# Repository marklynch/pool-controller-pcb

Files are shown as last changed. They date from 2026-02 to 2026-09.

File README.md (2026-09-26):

# Pool Controller PCB

KiCad design for a Connect 10 compatible pool-bus interface, using the finished **Waveshare ESP32-C6 Mini Development Board (ESP32-C6-Zero)** plugged into a carrier socket. The board provides a 5 V buck supply and single-wire receive/transmit interface. Firmware is maintained in [pool-controller-code](https://github.com/marklynch/pool-controller-code).

## Current revision

**Revision 15 is a prototype for validation.** It adds the 3.3 V RX clamp from [issue #3](https://github.com/marklynch/pool-controller-pcb/issues/3) and changes the TX base resistor to 560 Ω as proposed in [issue #4](https://github.com/marklynch/pool-controller-pcb/issues/4). It retains the existing 80 × 75 mm outline and 1.2 mm thickness.

The RX clamp requires the Waveshare 3.3 V rail and does not provide power-off isolation. Confirm operation during boot/reset/shutdown and at both 7 V and 12 V data-high levels before field use. The power-supply design report's detailed operating point is **5 V / 0.5 A**; a 5 A regulator IC does not make this a 5 A board.

See [revision 15 assembly and acceptance](docs/rev15-assembly.md) before ordering. J1/J2 now specify distributor-stocked Ckmtw R-RJ11R06P-A000 (LCSC C2902699), with a matching new footprint and connector routing. The original case has a 1.3 mm PCB slot, so retain the 1.2 mm board. Its RJ12 openings need enlargement: see [enclosure fit and same-case variant](docs/rev15-enclosure.md). Confirm snap-peg retention on the 1.2 mm board with PCBWay. The Waveshare boards have already been purchased separately; PCBWay should supply the soldered carrier and its two Samtec socket strips, with no additional module purchase.

## Files

- `PoolController.kicad_pro`, `.kicad_sch`, `.kicad_pcb`: source project, schematic and routed PCB.
- `components/`: project-specific symbols, footprints and existing 3D models.
- `docs/`: component/design references and prototype assembly instructions.
- `manufacturing/rev15/`: revision-specific sample-order exports and validation record.
- `scripts/export-manufacturing.sh`: reproduce manufacturing exports using KiCad 9.

Use **KiCad 9** to open and validate the project. Custom library paths are relative to the project. A 3D model is not a substitute for checking the dimensions and pin mapping of the actual purchased part.

## Ordering prototypes

For PCBWay, use `PCBWay-BOM.csv` (carrier parts only; Waveshare boards are customer-supplied) and `PCBWay-SMT-CPL.csv`. Read the assembly notes, confirm exact-part allocation and module installation, and review their DFM and placement previews before authorizing fabrication/assembly. Gerbers and drill files cover the bare board; the BOM, placement file and assembly drawing define fitted carrier parts. Fit the customer-owned module after delivery, or arrange consignment and separately quote installation/programming with PCBWay.

Physical checks, supplier approval, firmware programming and functional testing are distinct from KiCad ERC/DRC. Generated files are a prototype build package, not proof of field reliability.

## Licence

Hardware designs are licensed under the CERN Open Hardware Licence Version 2 — Permissive; see [LICENCE](LICENCE). See [CHANGELOG.md](CHANGELOG.md) for revision history.

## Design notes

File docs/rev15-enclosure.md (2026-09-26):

# Rev15 enclosure fit

Retain **1.2 mm PCB thickness**. The author's [pool-controller-case](https://github.com/marklynch/pool-controller-case) `BoxV7.FCStd`, commit `222a908dec85139a257c31b71b18a0f9f9488ca6`, defines a **1.3 mm** PCB slot (Sketch005). A 1.6 mm board would not fit that nominal slot. The PCB author changed thickness from 1.6 to 1.2 mm in [commit 07033f0](https://github.com/marklynch/pool-controller-pcb/commit/07033f06fe821ae59426765578216f9a735abf40). The commit does not explain the reason; the case geometry independently supports retaining 1.2 mm. Allow for board-thickness tolerance and printed-slot fit.

The **unmodified case is not compatible with the current RJ12 body envelopes**. Its front sketch has two 13.25 × 11.5 mm openings; the Ckmtw connector bodies are nominally 13.21 × 12.7 mm across the front. Their centres also differ slightly from the old openings. Do not order a printed original case expecting a verified fit.

`scripts/prepare-enclosure.py` generates a variant of the same case with 15 × 13.5 mm RJ12 openings centred on the current connector envelopes. It preserves the case exterior, PCB slot, lid geometry and USB opening. The script requires the author's external CAD as input and checks its SHA-256 before applying cuts. The output includes STL, editable STEP, the unchanged lid STL if supplied alongside the source, and a geometric collision report. It does not change the original FreeCAD file.

Example, with Python and CadQuery 2.8 installed:

```sh
python scripts/prepare-enclosure.py /path/to/pool-controller-case/BoxV7.FCStd /path/to/enclosure-rev15
```

The collision check covers only the nominal board and approximate RJ12 body envelopes. The connector drawing omits an explicit body-to-tail offset; the whole module/USB/header stack is not modelled. The generated solid was valid; nominal board-to-case, board-to-lid and RJ12-envelope collision volumes were zero after enlargement. A passing check is **not complete assembly validation**. Print one case and check the actual two sockets, cable latch operation, header engagement, module/USB access and lid clearance before printing the batch. Samtec socket body height is 8.51 mm; keep this exact socket MPN. The user already owns the Waveshare modules and will fit them after carrier delivery.

The RJ12 drawing recommends a 1.6 mm PCB. Retaining the case-compatible 1.2 mm carrier therefore still needs flush seating during soldering and a retention check; a thinner board would not remove this exception. The updated purchasing instructions state this requirement explicitly.

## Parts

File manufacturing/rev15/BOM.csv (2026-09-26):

Designator | Comment | Footprint | Manufacturer | MPN | Quantity | Supplier | Supplier Part | Supplier URL | Procurement note
C1 | 10nF | Capacitor_SMD:C_0805_2012Metric | TDK | C2012C0G1H103J060AA | 1 | DigiKey / manufacturer stock locator |  | https://product.tdk.com/en/search/capacitor/ceramic/mlcc/info?part_no=C2012C0G1H103J060AA | TDK Production; manufacturer recommended successor, 5% tolerance.
C2,C3 | C 10uF/63v | Capacitor_SMD:C_1210_3225Metric | Samsung Electro-Mechanics | CL32B106KMVNNWE | 2 | DigiKey |  | https://www.digikey.com/en/products/detail/samsung-electro-mechanics/CL32B106KMVNNWE/7320558 | Active distributor listing. 10uF 63V X7R; maximum height 2.8mm. Exact part only; qualify input ripple at 40V on samples.
C4 | 100nF/50v | Capacitor_SMD:C_0805_2012Metric | Kemet | C0805C104M5RACTU | 1 | DigiKey |  | https://www.digikey.com/en/products/detail/kemet/C0805C104M5RACTU/411168
C5 | C 47uF/16v | Capacitor_SMD:C_1210_3225Metric | Samsung Electro-Mechanics | CL32A476KOJNNNE | 1 | DigiKey |  | https://www.digikey.com/en/products/detail/samsung-electro-mechanics/CL32A476KOJNNNE/3889034 | Samsung Mass Production. Exact part only; qualify power-stage startup/load transients on samples.
D1,D2 | PMEG6010CEH,115 | Diode_SMD:D_SOD-123F | Nexperia | PMEG6010CEH,115 | 2 | LCSC | C110797 | https://www.lcsc.com/product-detail/C110797.html
D3 | BAT54 | Package_TO_SOT_SMD:SOT-23 | Nexperia | BAT54,215 | 1 | LCSC | C85084 | https://www.lcsc.com/product-detail/C85084.html
J1,J2 | RJ12 | PoolController:RJ12_Ckmtw_R-RJ11R06P-A000 | Ckmtw | R-RJ11R06P-A000 | 2 | LCSC | C2902699 | https://www.lcsc.com/product-detail/C2902699.html | 6P6C, tab down, right angle. Use new Ckmtw footprint only; original 5324 socket is not interchangeable. Verify retention on 1.2 mm PCB.
J3 | Header | Connector_PinHeader_2.54mm:PinHeader_1x04_P2.54mm_Vertical | XFCN | PZ254V-11-04P | 1 | LCSC | C2691448 | https://www.lcsc.com/product-detail/C2691448.html
J4,J5 | SSW-109-01-T-S | PoolController:Samtec_SSW-109-01-T-S_1x09 | Samtec | SSW-109-01-T-S | 2 | DigiKey |  | https://www.digikey.com/en/products/detail/samtec-inc/SSW-109-01-T-S/1112296 | Two 9-position socket strips per carrier; tin contacts and tails, 8.51mm body height. Do not substitute taller/shorter sockets without mechanical review.
L1 | L 120uH | Inductor_SMD:L_10.4x10.4_H4.8 | Bourns | SRR1050HA-121Y | 1 | DigiKey |  | https://www.digikey.com/en/products/detail/bourns-inc/SRR1050HA-121Y/16883859 | Active HA series; 245 C maximum reflow peak.
Q1 | MMBT3904 | MMBT3904:SOT-23_MCC | Guangdong Hottech | MMBT3904 | 1 | LCSC | C181119 | https://www.lcsc.com/product-detail/C181119.html | Use specified Guangdong Hottech manufacturer.
R1,R2,R4 | R100k | Resistor_SMD:R_0603_1608Metric | YAGEO | RC0603FR-07100KL | 3 | LCSC | C14675 | https://www.lcsc.com/product-detail/C14675.html
R3 | R560 | Resistor_SMD:R_0603_1608Metric | YAGEO | RC0603FR-07560RL | 1 | Mouser |  | https://au.mouser.com/en/ProductDetail/YAGEO/RC0603FR-07560RL | Mouser stock observed; DigiKey backordered at review. Confirm allocation.
U1 | LM2678S-5.0/NOPB | Package_TO_SOT_SMD:TO-263-7_TabPin4 | Texas Instruments | LM2678S-5.0/NOPB | 1 | DigiKey |  | https://www.digikey.com/en/products/detail/texas-instruments/LM2678S-5-0-NOPB/363825 | Confirm 245 C peak reflow limit and thermal-pad via treatment.

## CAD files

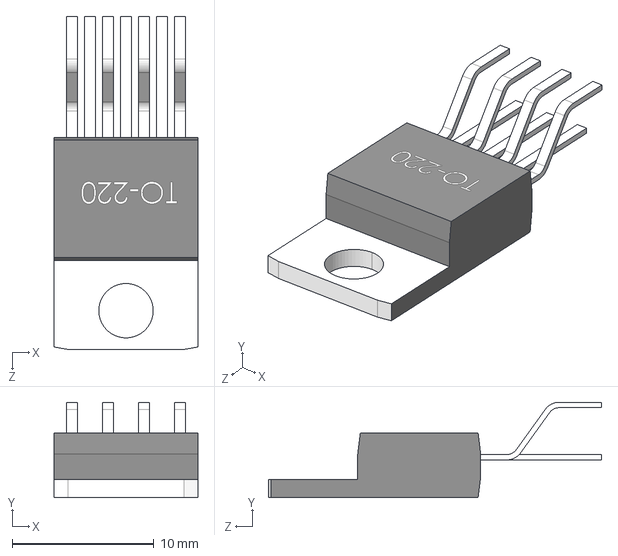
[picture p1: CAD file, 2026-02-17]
components/3dmodels/TO-220-7.step
10.2 x 6.74 x 23.5 mm

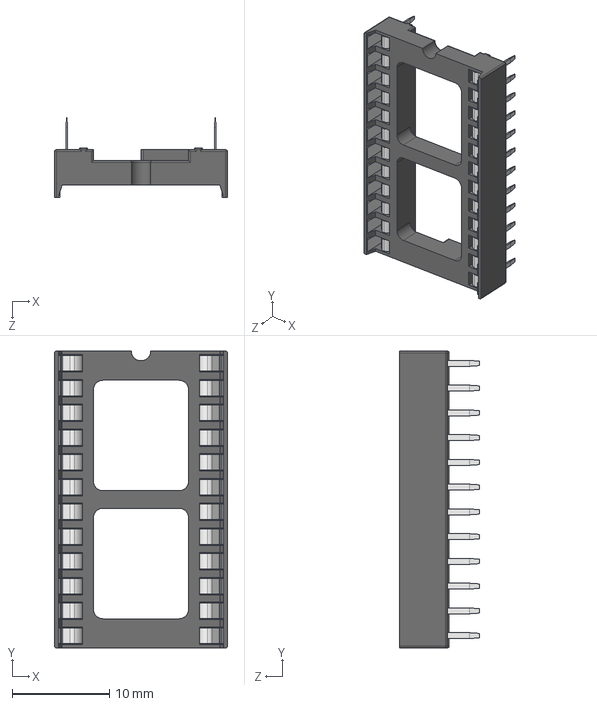
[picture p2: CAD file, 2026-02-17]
components/3dmodels/DIP-24_18.0mmx34.29mm_W15.24mm.step
17.8 x 30.5 x 8.20 mm
board-24_По умолчанию
pin_По умолчанию x 24

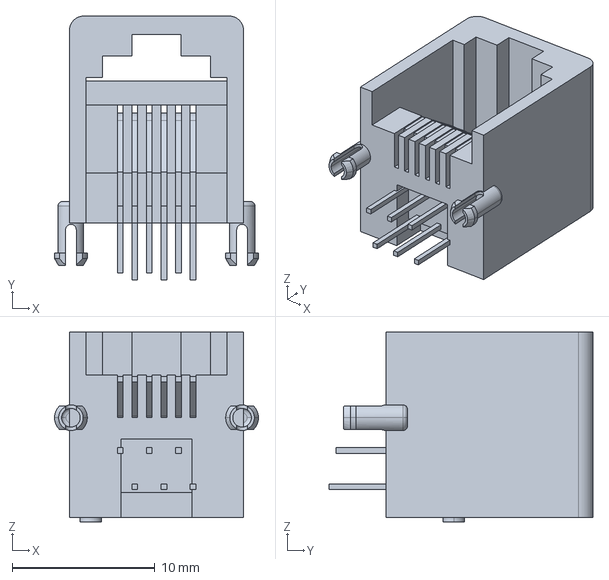
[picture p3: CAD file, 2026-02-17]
components/3dmodels/52018-6646.stp
14.3 x 18.5 x 13.3 mm

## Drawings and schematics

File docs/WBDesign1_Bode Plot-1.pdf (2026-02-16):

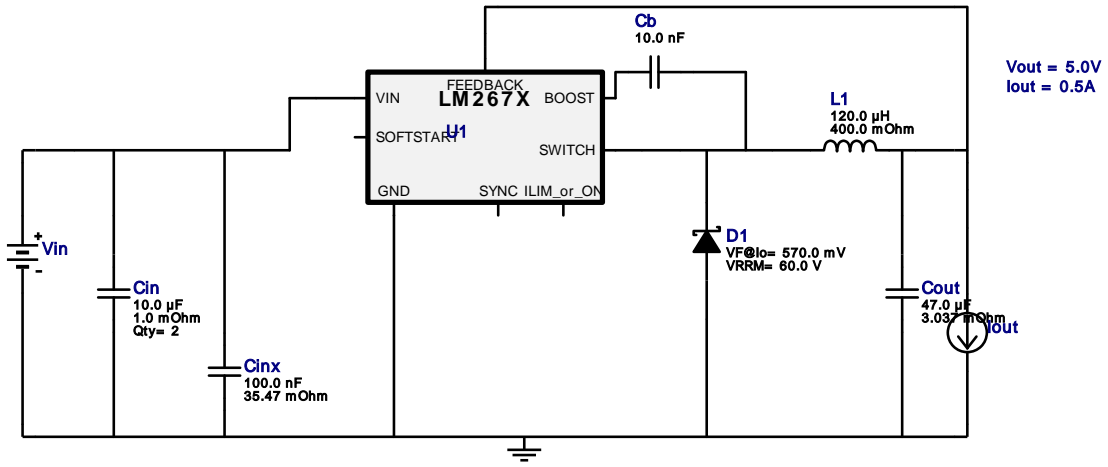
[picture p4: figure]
VIN; FEEDBACK; BOOST; SWITCH; GND; SYNC ILIM_or_ON; SOFTSTARTU1; Cin 10.0 µF 1.0 m Ohm Qty= 2; Cinx 100.0 nF 35.47 m Ohm; Vout = 5.0V Iout = 0.5A; Cout 47.0 µF 3.037 m Ohm; D1 VF@Io= 570.0 m V VRRM= 60.0 V; L1 120.0 µH 400.0 m Ohm; Vin; Iout

Copyright © 2026, Texas Instruments Incorporated | 1 | ti.com/webench

WEBENCH®
Design Report LM2678SX-5.0/NOPB : LM2678SX-5.0/ NOPB 20V-40V to 5.00V @ 2.5A February 15, 2026 15:06:18 GMT-06:00

## WEBENCH ® Design Report

Design : 1 LM2678SX-5.0/NOPB
LM2678SX-5.0/NOPB 20V-40V to 5.00V @ 2.5A

VinMin = 20.0V
VinMax = 40.0V
Vout = 5.0V
Iout = 0.5A

Device = LM2678SX-5.0/NOPB Topology = Buck
Created = 2026-02-15 15:02:31.291 BOM Cost = $4.09
BOM Count = 8
Total Pd = 0.57W
1. The small series "trace inductance", particularly from the Switch Output pin, can create a high frequency (10's of MHz) ringing signal at the switch output. If problematic, this ringing can be reduced or eliminated by the use of a series RC damper or snubber network from the switch output to ground. Values of 0.01 uF and 10 ohm are good starting values that may need to be varied depending on the magnitude of parasitic factors in a given design. In an actual end application, these components are normally not required if proper care to minimize trace lengths is taken in the PCB design.

## Electrical BOM

Name | Manufacturer | Part Number | Properties | Qty Price | Footprint
Cb | TDK | C2012C0G1H103K060AA (http://product.tdk.com/capacitor/mlcc/en/documents/mlcc%5Fcommercial%5Fgeneral%5Fen.pdf) Series= C0G/NP0 | Cap= 10.0 nF VDC= 50.0 V IRMS= 0.0 A
1 | $0.07
| | | | | 0805 7 mm²
Cin | MuRata | GRM32ER71J106KA12L (http://psearch.en.murata.com/capacitor/product/GRM32ER71J106KA12%23.pdf) Series= X7R | Cap= 10.0 uF ESR= 1.0 mOhm VDC= 63.0 V IRMS= 6.0 A
2 | $0.30
| | | | | 1210_280 15 mm²
Cinx | Kemet | C0805C104M5RACTU (http://capacitoredge.kemet.com/capedge2/DataSheet/Datasheet%2DC0805C104M5RACTU.pdf?pn%3DC0805C104M5RACTU) Series= X7R | Cap= 100.0 nF ESR= 35.47 mOhm VDC= 50.0 V IRMS= 1.64 A
1 | $0.01
| | | | | 0805 7 mm²
Cout | MuRata | GRM32ER61C476KE15L (http://psearch.en.murata.com/capacitor/result/smd/?status%3Dall%26pid%3DGRM32ER61C476KE15L) Series= X5R | Cap= 47.0 uF ESR= 3.037 mOhm VDC= 16.0 V IRMS= 4.59346 A
1 | $0.17
1210_280 15 mm²
D1 | Nexperia | PMEG6010CEH,115 (http://www.nxp.com/documents/data%5Fsheet/PMEG6010CEH%5FPMEG6010CEJ.pdf) | VF@Io= 570.0 mV VRRM= 60.0 V
1 | $0.04
SOD-123F 12 mm²
L1 | NIC Components | NPI105C121MTRF (http://www.niccomp.com/pn/NPI105C121MTRF) | L= 120.0 µH 400.0 mOhm
1 | $0.23

IND_NPI105C 141 mm²

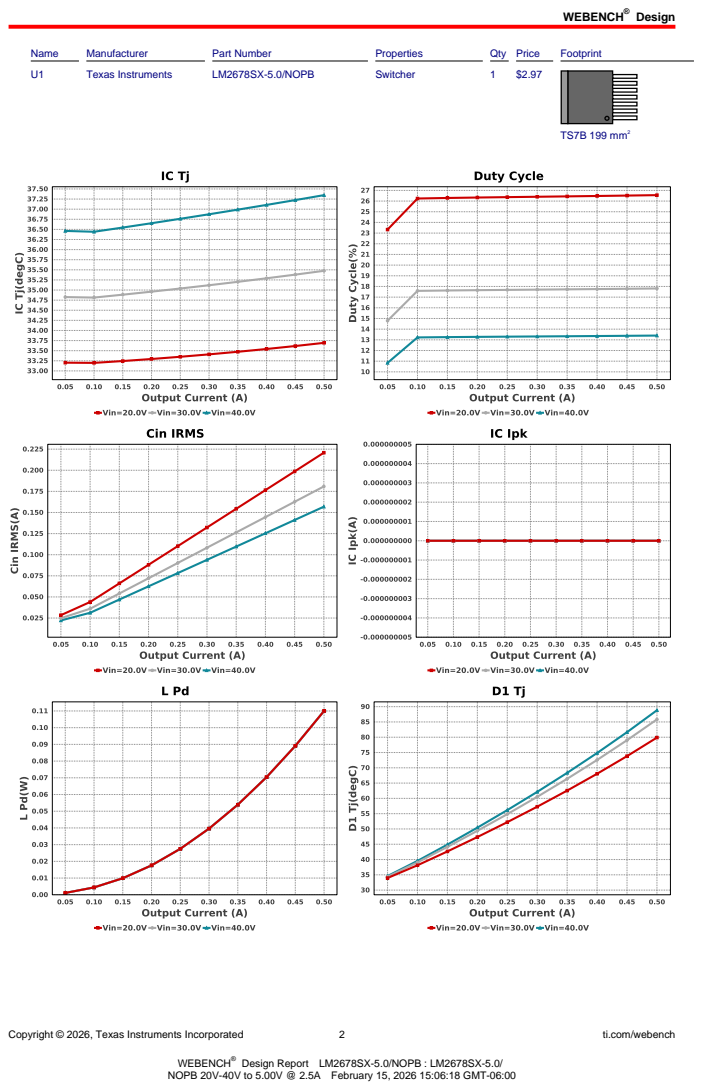
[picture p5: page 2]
Design; Copyright © 2026, Texas Instruments Incorporated; ti.com/webench; Name; Manufacturer; Part Number; Properties; Qty Price; Footprint; Texas Instruments; LM2678SX-5.0/NOPB; Switcher; TS7B 199 mm²

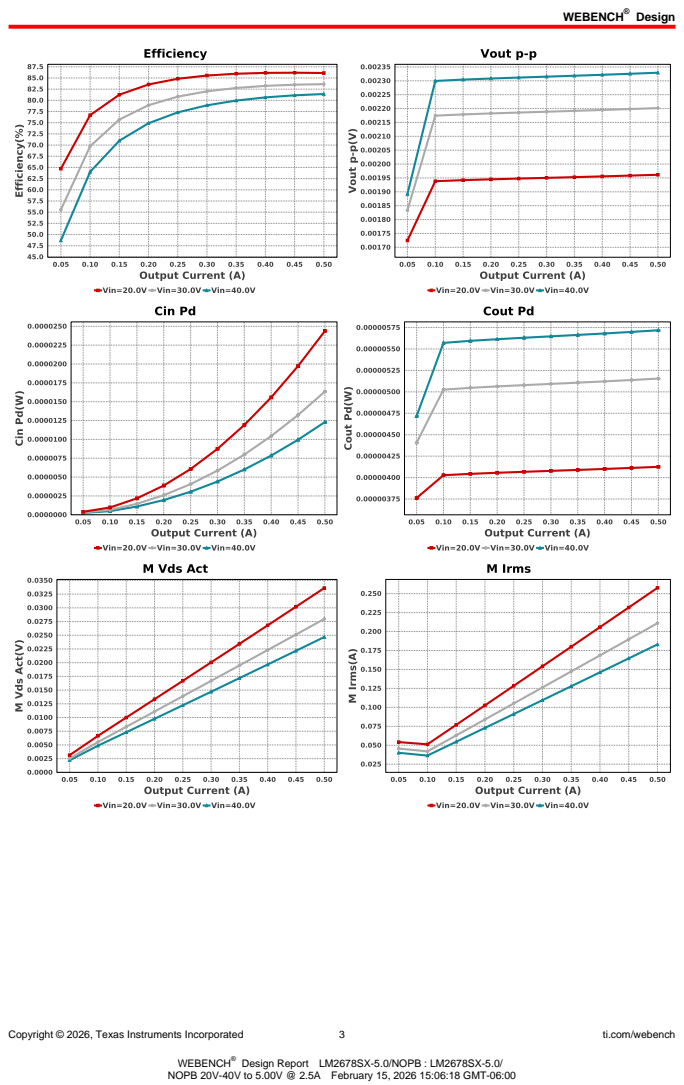
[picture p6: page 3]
Copyright © 2026, Texas Instruments Incorporated; ti.com/webench

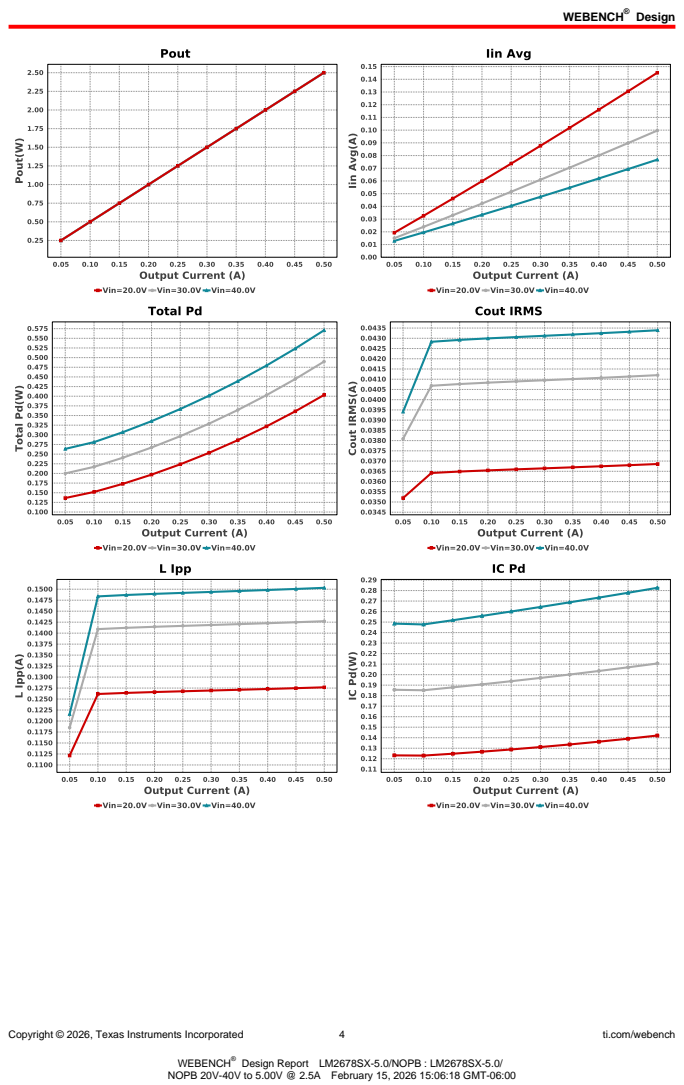
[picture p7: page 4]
Copyright © 2026, Texas Instruments Incorporated; ti.com/webench

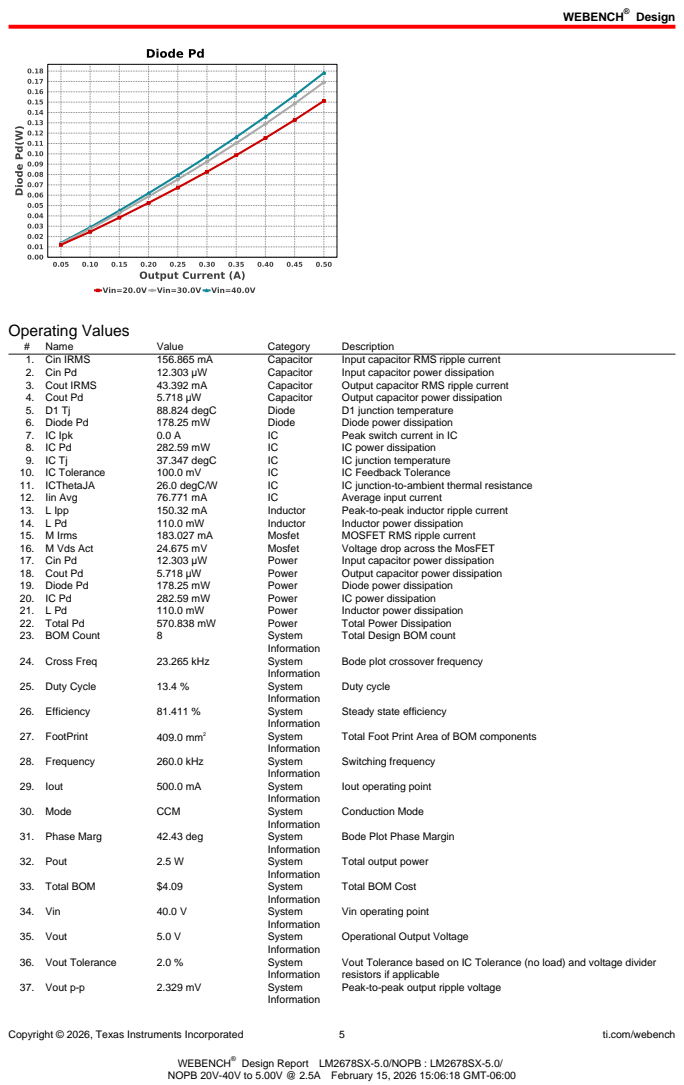
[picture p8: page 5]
Copyright © 2026, Texas Instruments Incorporated; ti.com/webench; Operating Values; Name; Value; Category; Description; 1. Cin IRMS; Capacitor; Input capacitor RMS ripple current; 2. Cin Pd; Input capacitor power dissipation; 3. Cout IRMS; Output capacitor RMS ripple current; 4. Cout Pd; Output capacitor power dissipation; 88.824 degC; Diode; D1 junction temperature; 6. Diode Pd; Diode power dissipation; 7. IC Ipk; Peak switch current in IC; IC power dissipation; 37.347 degC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

Total Design BOM count

Bode plot crossover frequency

Steady state efficiency

Total Foot Print Area of BOM components

Iout operating point

Bode Plot Phase Margin

Total output power

Total BOM Cost

Vin operating point

Operational Output Voltage

Vout Tolerance based on IC Tolerance (no load) and voltage divider
resistors if applicable
Peak-to-peak output ripple voltage

Copyright © 2026, Texas Instruments Incorporated | 6 | ti.com/webench

## Design Inputs

Name | Value | Description
Iout | 500.0 m | Maximum Output Current
VinMax | 40.0 | Maximum input voltage
VinMin | 20.0 | Minimum input voltage
Vout | 5.0 | Output Voltage
base_pn | LM2678 | Base Product Number
source | DC | Input Source Type
Ta | 30.0 | Ambient temperature


Copyright © 2026, Texas Instruments Incorporated | 7 | ti.com/webench

## Assembly
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

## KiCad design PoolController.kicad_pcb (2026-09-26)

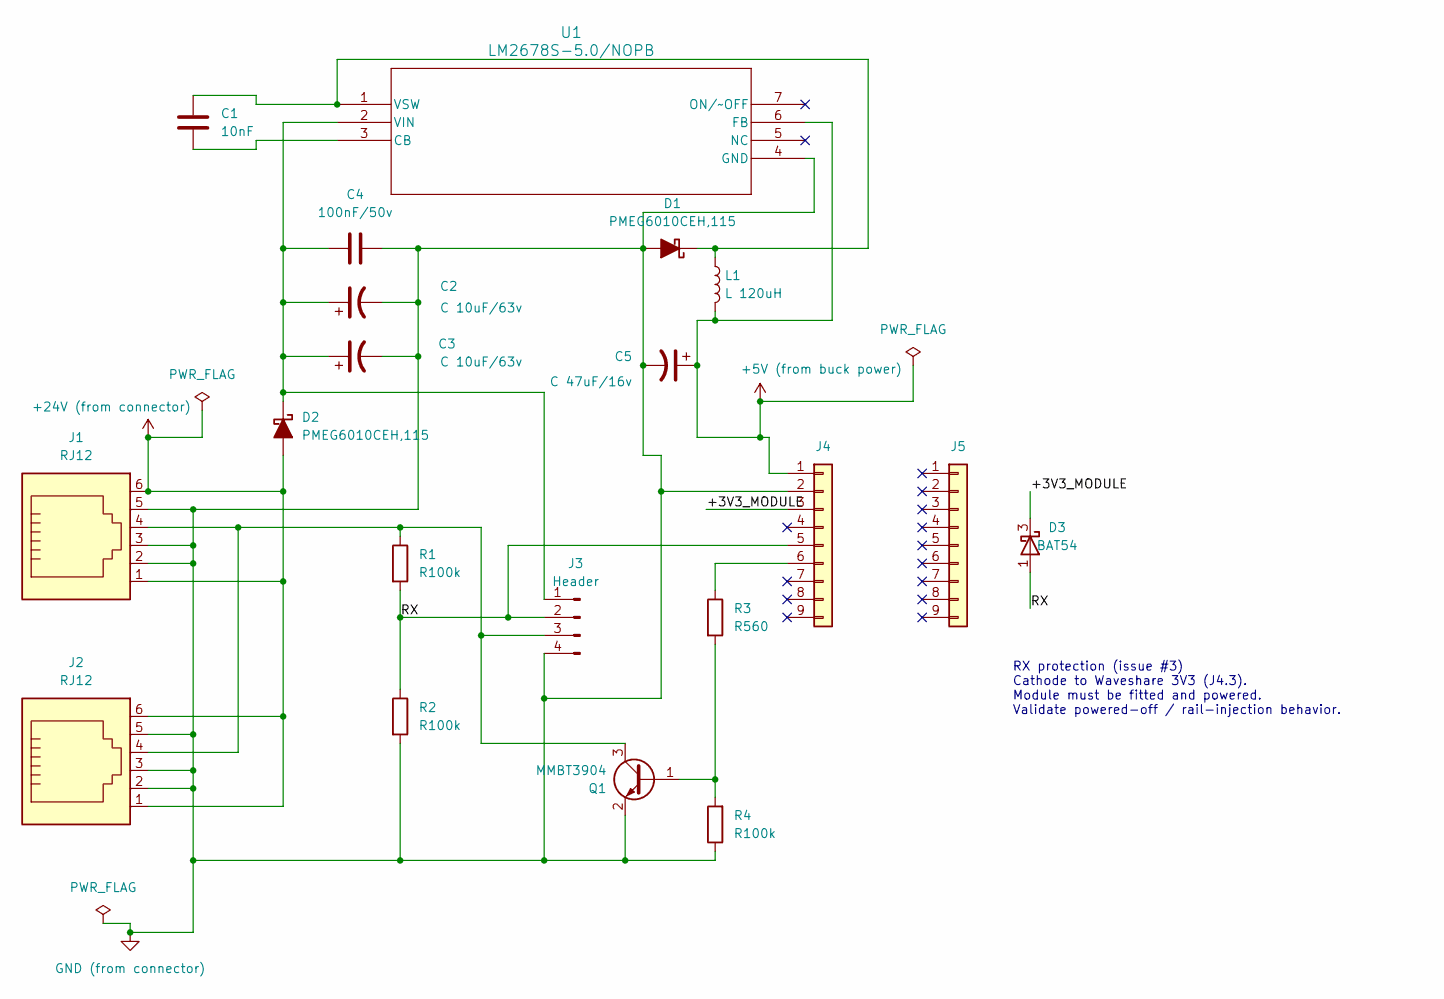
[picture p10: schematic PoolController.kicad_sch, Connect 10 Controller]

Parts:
C1: 10nF; C_0805_2012Metric; MPN C2012C0G1H103J060AA
C2, C3: C 10uF/63v; C_1210_3225Metric; MPN CL32B106KMVNNWE
C4: 100nF/50v; C_0805_2012Metric; MPN C0805C104M5RACTU
C5: C 47uF/16v; C_1210_3225Metric; MPN CL32A476KOJNNNE
D1, D2: PMEG6010CEH,115; D_SOD-123F; MPN PMEG6010CEH,115
D3: BAT54; SOT-23; MPN BAT54,215
J1, J2: RJ12; RJ12_Ckmtw_R-RJ11R06P-A000; MPN R-RJ11R06P-A000
J3: Header; PinHeader_1x04_P2.54mm_Vertical; MPN PZ254V-11-04P
J4, J5: SSW-109-01-T-S; Samtec_SSW-109-01-T-S_1x09; MPN SSW-109-01-T-S
L1: L 120uH; L_10.4x10.4_H4.8; MPN SRR1050HA-121Y
Q1: MMBT3904; SOT-23_MCC; MPN MMBT3904
R1, R2, R4: R100k; R_0603_1608Metric; MPN RC0603FR-07100KL
R3: R560; R_0603_1608Metric; MPN RC0603FR-07560RL
U1: LM2678S-5.0/NOPB; TO-263-7_TabPin4; MPN LM2678S-5.0/NOPB

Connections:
+5V (from buck power): C5.1, J4.1, L1.2, U1.6 (FB)
+24V (from connector): D2.2 (A), J1.1, J1.6, J2.1, J2.6
/+3V3_MODULE: D3.3 (K), J4.3
/RX: D3.1 (A), J3.2, J4.5, R1.2, R2.1
GND (from connector): C2.2, C3.2, C4.2, C5.2, D1.2 (A), J1.2, J1.3, J1.5, J2.2, J2.3, J2.5, J3.4, J4.2, Q1.2 (E), R2.2, R4.1, U1.4 (GND)
unnamed: C1.1, D1.1 (K), L1.1, U1.1 (VSW)
unnamed: C2.1, C3.1, C4.1, D2.1 (K), J3.1, U1.2 (VIN)
unnamed: J1.4, J2.4, J3.3, Q1.3 (C), R1.1
unnamed: J4.6, R3.1
unnamed: Q1.1 (B), R3.2, R4.2
unnamed: C1.2, U1.3 (CB)

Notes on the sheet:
RX protection (issue #3) Cathode to Waveshare 3V3 (J4.3). Module must be fitted and powered. Validate powered-off / rail-injection behavior.

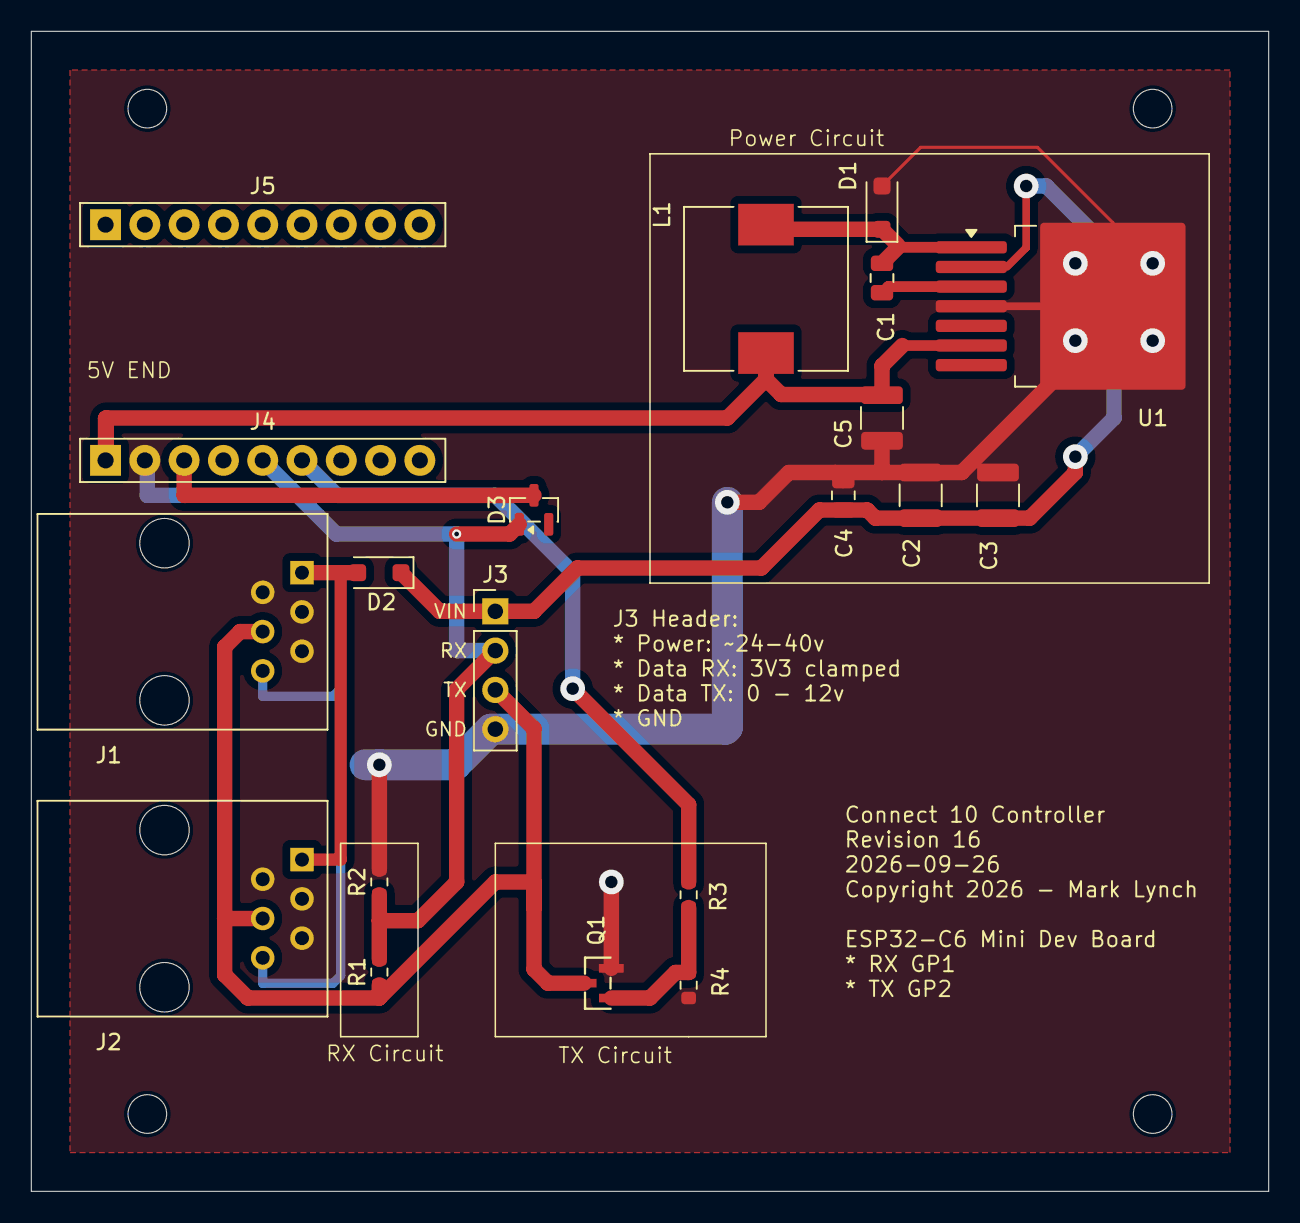
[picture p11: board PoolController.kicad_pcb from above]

Board: 2 copper layers, 80.0 x 75.0 mm, 20 parts (0 on the bottom side), 11 nets.

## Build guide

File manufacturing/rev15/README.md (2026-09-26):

# Rev15 prototype manufacturing package

**Use for a PCBWay prototype quotation; confirm exact-part sourcing and mechanical/process requirements before build.** Use [PCBWay upload and quote instructions](PCBWay-instructions.md). Read [assembly and acceptance requirements](../../docs/rev15-assembly.md) with the supplier. No physical prototypes have yet been validated for this revision.

- `PCBWay-package.zip`: convenient download containing the PCBWay upload files and assembly instructions. Unzip it before uploading the separate fabrication/BOM/centroid files.
- `fabrication.zip`: two copper layers, mask, silkscreen, paste, outline, Gerber job file and separate plated/non-plated Excellon drills. Order **80 × 75 mm, 1.2 mm FR-4, nominal 1 oz copper per side**. Approve finish, panel tooling and thermal-pad via treatment with the assembler.
- `BOM.csv`: 20 carrier components (15 SMT and 5 through-hole). J1/J2 specify Ckmtw R-RJ11R06P-A000 / LCSC C2902699. All carrier parts have nominated supplier links. Current capacitor/inductor MPNs replace the prior legacy lines; J4/J5 use two active Samtec nine-position strips.
- `PCBWay-BOM.csv`: use for the carrier quote; includes all 20 carrier components. Waveshare boards are already customer-owned and must not be purchased again.
- `PCBWay-SMT-CPL.csv`: use as PCBWay’s SMT centroid file (15 SMT parts). The five through-hole components and module fitting are covered by the BOM/drawing/instructions.
- `CPL.csv`: native KiCad CSV placement data, **millimetres, absolute board origin**, front side for all 20 references. Negative Y coordinates follow KiCad's exported Cartesian convention; no origin translation or rotation correction has been applied. Includes through-hole parts. Map `Ref/PosX/PosY/Rot/Side` to the supplier's placement fields and approve every orientation in their preview, especially D3, Q1, U1, RJ12 and J4. Footprint origins are the source placement references; the assembler may adjust feeder/centroid conventions.
- `assembly.pdf`, `schematic.pdf`, `copper.pdf`: reference drawings (front assembly, circuit, and front/back copper respectively).
- `erc.json`, `drc.json`: native KiCad checks including schematic parity, required to pass before export.
- `manifest.json`: KiCad version and SHA-256 fingerprints of source and order artifacts. Regenerate whenever the design changes; do not mix revisions.

The **Waveshare development boards have already been purchased separately** and are excluded from PCBWay procurement. Fit them after delivery, or arrange customer consignment and separately quote header fitting if needed, correct-end insertion, programming and functional tests. Do not assume they are included in automated SMT assembly.

## Regeneration

Use KiCad 9 with its standard symbol/footprint libraries installed, plus Python 3. Refill zones and save the PCB in KiCad, then run from the checkout:

```sh
scripts/export-manufacturing.sh
# Or select a specific KiCad 9 CLI:
KICAD_CLI=/path/to/kicad-cli scripts/export-manufacturing.sh
```

The script requires clean ERC, DRC and schematic parity, checks the 20-reference BOM/placement set and selected revision-specific MPNs, then replaces the generated artifacts. It does not order boards or certify electrical behavior. Timestamps and PDF metadata can differ between export runs; use the manifest to identify this exact package.

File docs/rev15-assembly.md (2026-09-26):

# Revision 15 — prototype assembly and acceptance

Revision 15 implements the powered RX clamp proposed in [issue #3](https://github.com/marklynch/pool-controller-pcb/issues/3) and the 560 Ω TX base drive from [issue #4](https://github.com/marklynch/pool-controller-pcb/issues/4). It is a prototype revision: KiCad checks and manufacturing outputs do not establish operation on every Connect 10 installation.

## Circuit changes

- D3 = **Nexperia BAT54,215**, single Schottky diode, SOT-23. Pin 1/anode connects to RX; pin 3/cathode connects to the Waveshare 3.3 V rail through J4 pin 3; pin 2 is not connected. Do not substitute BAT54A, BAT54C or BAT54S dual-diode variants.
- R3 = **560 Ω, Yageo RC0603FR-07560RL**, replacing 1 kΩ. This is the TX base resistor, called R4 in older issue descriptions. Current R4 remains **100 kΩ** from base to ground.
- R1/R2 remain 100 kΩ. The clamp diverts excess RX current into the powered module's 3.3 V rail; it is not an isolated receiver or a guaranteed power-off-safe interface.
- L1 is **Bourns SRR1050HA-121Y**, the current HA-series 120 µH part. Its nominal package and recommended lands match the previous SRR1050A part. The original WEBENCH report used a different inductor; repeat power-supply acceptance with the actual fitted part.

### Current-part replacements

| Ref | Fitted MPN | Basis |
|---|---|---|
| C1 | TDK C2012C0G1H103J060AA | Production; TDK-recommended successor, 10 nF/50 V/C0G/0805, tolerance improves to 5% |
| C2/C3 | Samsung CL32B106KMVNNWE | Distributor Active; 10 µF/63 V/X7R/1210; maximum height 2.8 mm |
| C5 | Samsung CL32A476KOJNNNE | Manufacturer Mass Production; 47 µF/16 V/X5R/1210 |
| L1 | Bourns SRR1050HA-121Y | Distributor Active; 120 µH, same nominal body and land pattern |
| J4/J5 | Samtec SSW-109-01-T-S, two strips | Active nine-position sockets for standard 0.025-inch square header posts; tin contacts/tails |

These replace the former NRND capacitors/inductor and obsolete DIP socket. Supplier links are included in the purchasing BOM. C2/C3's accessible manufacturer data does not provide DC-bias capacitance at 40 V: their effective capacitance equivalence is unverified. C5's manufacturer curve gives about 27.65 µF typical at 5 V, close to the original Murata's approximately 28 µF, but neither that comparison nor nominal ratings establish regulator stability. Qualify input ripple, startup and load steps on the sample build before field use. No automatic power-stage substitutions.

## Order definition

| Item | Specification |
|---|---|
| Board | 80 × 75 mm, two layers, FR-4, **1.2 mm** thickness |
| Copper | 35 µm / nominal 1 oz per side |
| Components | Front-side SMT plus through-hole connectors/socket |
| Finish | Agree with assembler; keep board thickness at 1.2 mm for mechanical fit |
| Quantity | Small prototype batch; price depends on quantity, sourcing and manual assembly |
| Assembly process | Use a reflow profile within both LM2678S-5.0/NOPB and SRR1050HA-121Y limits (245 °C maximum peak). Do not select a hotter process without manufacturer/assembler approval. |
| U1 thermal pad | Four existing 0.8 mm drilled ground vias within the thermal pad; tenting is requested, not filled/capped vias. Assembler must approve paste and via treatment. |
| Inspection | Electrical bare-board test, assembly polarity/placement inspection, then functional acceptance below |

[PCBWay supports mixed SMT/through-hole assembly](https://www.pcbway.com/assembly-capabilities.html) and [turnkey, nominated-distributor, consigned or combined sourcing](https://www.pcbway.com/pcb_prototype/Electronic_Components.html). Request **turnkey PCB fabrication plus mixed assembly** with the PCBWay-specific BOM and SMT centroid in the manufacturing folder. PCBWay's published capabilities support these package types; only their reviewed quote can confirm every exact part, lead time, reflow profile and manual installation service. No order or quote has been submitted.

### RJ12 sockets: specified distributor part

J1/J2 are **Ckmtw R-RJ11R06P-A000**, **LCSC C2902699**, quantity **2 per carrier**. [Distributor product/source](https://www.lcsc.com/product-detail/C2902699.html), [manufacturer drawing through LCSC](https://www.lcsc.com/datasheet/C2902699.pdf). Although marketed as RJ11, the drawing explicitly specifies six positions and six contacts (6P6C), suitable for the requested RJ12 connection. Do not substitute a four-contact socket.

The board now uses a dedicated project footprint derived from drawing **C2902699, revision A**: 1.27 mm contact progression, 2.54 mm row spacing, six 0.90 mm plated holes, and two 3.20 mm non-plated retention holes spaced 10.16 mm. Contacts 1/6 carry supply, 2/3/5 ground, and 4 bus data, preserving schematic numbering. Connector-region supply/data routing and ground connections were updated for the new holes.

This is a **larger, tab-down connector**, approximately 13.21 mm wide × 20.54 mm deep × 12.70 mm high. It replaces the original 5324 mini geometry; the two parts are not interchangeable. Connector origins are now J1 (82.50, 75.00) and J2 (82.50, 93.55) mm, rotated −90°. The mating face overhangs the left PCB edge. The body-to-tail offset is not dimensioned in the supplier drawing: the fabrication outline is an approximate envelope and the courtyard allows extra clearance. The original enclosure openings are too small. Use the same-case variant described in [enclosure fit](rev15-enclosure.md), and check the actual part before printing a batch. Silkscreen is clipped back inside the PCB and does not represent the overhanging face.

LCSC displayed stock at review on 2026-09-12; stock is not reserved and PCBWay must confirm procurement. The drawing calls out a 1.6 mm PCB, whereas this carrier retains its required **1.2 mm** thickness. Ask PCBWay to confirm the snap-peg seating/retention on 1.2 mm and hold the connector flush during soldering if necessary. Through-hole solder joints and the final mechanical fit require inspection. The obsolete approximate Wayconn 3D model is not used for these connectors.

### Full-BOM sourcing check for PCBWay

The BOM now includes nominated supplier links for every carrier MPN. These are evidenced procurement routes, not a PCBWay stock commitment. See [procurement data](../manufacturing/procurement.json) for the exact links used by the exporter.

- Use the exact current-part replacements above. This removes the previously identified NRND/obsolete purchasing lines. Stock remains subject to distributor allocation at quote time; no parts have been reserved.
- J4/J5 use identical Samtec socket strips, **quantity two per carrier**. Install both flush and parallel, 15.24 mm between row centres. The manufacturer body height is 8.51 mm; do not change socket height without checking the module and case.
- **D1/D2** have a stocked LCSC route (C110797) despite DigiKey backorder. **R3** has a Mouser route despite DigiKey backorder. The other BOM lines have distributor listings with stock at review. PCBWay may need procurement minimums and assembly overage beyond fitted quantities.
- Approve U1's reflow limit and thermal-pad via treatment, as above. Confirm tooling/fiducials with PCBWay; mounting holes are not an approved tooling-hole pattern.

### Waveshare module: already purchased by customer

The customer has already ordered the finished **Waveshare ESP32-C6 Mini Development Boards** separately. **Do not procure additional modules.** The PCBWay purchasing BOM includes only the carrier's **two Samtec SSW-109-01-T-S socket strips**, not a Waveshare board. The default build scope is a fully soldered carrier; the customer fits their module after delivery.

If PCBWay is to install the customer-owned modules, arrange **combo/consigned assembly** and quote insertion separately before shipping them. Confirm the exact supplied variant and header state: Waveshare's **ESP32-C6-Zero-M** has presoldered headers, while the unheaded variant needs compatible headers fitted first. The already-ordered variant has not been independently identified. [Waveshare product and variants](https://www.waveshare.com/product/arduino/esp32-c6-zero.htm). Module programming and functional tests are not included without an agreed firmware version and test procedure.

Align the module's **5V pin to J4 pin 1 at the marked socket end**, GND to pin 2, 3V3 to pin 3, GPIO1 to pin 5 and GPIO2 to pin 6. The two strips have nine contacts each, matching the module's two nine-pin rows. J5 is the opposite, electrically unconnected support row. Do not rotate the module 180 degrees. Verify row spacing, header/socket contact compatibility, seating height, USB access and antenna clearance with the exact supplied board and enclosure. No approximate module/socket 3D model is used to claim enclosure fit.

Use Waveshare's [schematic and mechanical resources](https://docs.waveshare.com/ESP32-C6-Zero/Resources-And-Documents) for the exact supplied variant. Do not interchange a similarly named third-party “SuperMini” board. Supply the firmware release/version and programming requirements separately if functional units must arrive ready to run.

## Functional acceptance for samples

Perform powered tests with a current-limited source and known bus simulator before connecting a pool system. Establish the actual installation's supply/transient and data-high ranges rather than relying on the silkscreen's nominal values.

1. Inspect D3/Q1 pin orientation, all connector pins, and the module insertion. Measure absence of unintended supply-to-ground shorts before power-up. Verify RX to D3 anode, cathode to module 3V3, and continuity of the intended RJ12 pin mapping.
2. With the module removed, test the buck converter at the intended input range up to 40 V with 0–0.5 A loads. Scope output startup, ripple, load transients, ringing and component temperatures. This board is not rated for a 5 A output simply because the IC is a 5 A regulator.
3. Fit the module before applying a data signal. Scope **both RX and the 3.3 V rail** at 7 V and 12 V data-high, including resistor tolerances and actual bus source impedance. Check VIH/VIL against the ESP32-C6 datasheet and verify the clamp does not lift the rail.
4. Repeat during boot, reset, low-load/sleep states and shutdown. At nominal 12 V with RX around 3.54 V, approximately 49 µA enters the 3.3 V rail. With an unpowered rail, current can approach 0.12 mA. The design must not be treated as providing power-off isolation. If the actual operating sequence leaves a driven bus connected to an unpowered module and measurements exceed allowed limits, revise the receiver before field use.
5. Check temperatures relevant to the enclosure. The BAT54 forward-voltage bound used in the nominal analysis is a 25 °C test condition, not an all-temperature clamp guarantee.
6. Confirm TX can pull low against the real bus load at both high levels, with the exact MMBT3904 supplied. Scope low level and release edges; test sustained bidirectional traffic alongside existing devices and check for stuck-low or intermittent operation.
7. Verify pool-only, USB-only and simultaneous-power behavior with the exact Waveshare board, then Wi-Fi/firmware operation in the case. Confirm cable pin mapping before connection to actual equipment.

Do not connect the bus to an empty J4 socket or assume the clamp makes all unpowered states safe. Reject samples with unexplained rail rise, excessive RX voltage, unstable supply, communication faults or poor soldering.

## References

- [Nexperia BAT54 datasheet](https://assets.nexperia.com/documents/data-sheet/BAT54.pdf): single-diode pinning and forward characteristics.
- [Espressif ESP32-C6 datasheet](https://documentation.espressif.com/esp32-c6_datasheet_en.html): GPIO input levels relative to its supply domain.
- [Bourns SRR1050HA datasheet](https://www.bourns.com/docs/product-datasheets/srr1050ha.pdf): lands, electrical and reflow limits.
- [TI LM2678 datasheet](https://www.ti.com/lit/gpn/lm2678): power/layout and reflow requirements.

- [TDK C1 production record](https://product.tdk.com/en/search/capacitor/ceramic/mlcc/info?part_no=C2012C0G1H103J060AA).
- [Samsung C2/C3 specifications](https://weblib.samsungsem.com/mlcc/mlcc-ec-data-sheet.do?partNumber=CL32B106KMVNNW).
- [Samsung C5 production record and curves](https://product.samsungsem.com/mlcc/CL32A476KOJNNN.do).
- [Samtec SSW product](https://www.samtec.com/products/ssw-109-01-t-s), [body drawing](https://suddendocs.samtec.com/prints/ssw-1xx-xx-xxx-x-xx-xxx-xx-mkt.pdf), [recommended hole pattern](https://suddendocs.samtec.com/prints/ssw-s.pdf): 1.04 mm holes at 2.54 mm pitch.

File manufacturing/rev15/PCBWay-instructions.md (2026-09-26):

# PCBWay sample assembly instructions

Request a **turnkey fabrication and mixed SMT/through-hole assembly quote** using the current revision 15 files. Quantities in the BOM are **per finished unit**; select the desired sample batch quantity in the quote. Allow supplier minimums and assembly overage separately.

Upload:

1. `fabrication.zip` — 80 × 75 mm, two-layer FR-4, **1.2 mm**, nominal 1 oz copper each side.
2. `PCBWay-BOM.csv` — 20 fitted carrier parts; all exact carrier MPNs have suggested source links. Waveshare modules have already been purchased by the customer and are excluded.
3. `PCBWay-SMT-CPL.csv` — 15 SMT components, mm, absolute origin, top side; map KiCad column names if requested. Do not translate the origin independently of the fabrication files.
4. `assembly.pdf`, `schematic.pdf` and `docs/rev15-assembly.md` — reference drawings and acceptance requirements. `CPL.csv` also supplies all 20 carrier placements for engineering review.

Include J1/J2/J3/J4/J5 through-hole fitting in the price. **Do not purchase Waveshare modules.** Deliver fully soldered carriers for the customer to fit their existing modules. If the customer instead consigns modules to PCBWay, quote insertion separately. Use Ckmtw **R-RJ11R06P-A000**, LCSC **C2902699**, for both RJ12 sockets. This package has new connector holes/routing; do not reuse the earlier revision 15 fabrication ZIP or the original 5324 mini sockets.

Before accepting the quote, obtain PCBWay's confirmation of:

- Exact MPN procurement and quantities, including the exact current capacitor/inductor and Samtec socket MPNs. No automatic substitutions.
- Regulator and inductor maximum peak reflow temperature of 245 °C; handling of four drilled/tented, unfilled thermal-pad vias; tooling/panel rails and fiducials.
- RJ12 snap-peg fit on **1.2 mm** PCB (drawing specifies 1.6 mm). Hold parts flush during soldering as needed. The original enclosure openings need enlargement; see docs/rev15-enclosure.md. The body envelope in the drawing is approximate; the numbered hole pattern follows the manufacturer drawing.
- For any customer-consigned Waveshare modules, confirm the actual variant/header state, header/socket compatibility and correct-end insertion: 5V to J4.1, GND to J4.2, 3V3 to J4.3. J4/J5 are two nine-position strips, quantity two; install flush and parallel at 15.24 mm row spacing.
- Programming and functional testing only against an explicitly supplied firmware binary/version and test procedure. A fully soldered board is not automatically programmed or functionally accepted.

PCBWay's published sourcing and mixed-assembly capabilities support this quote route. No PCBWay review, stock reservation, exact-part acceptance or purchase is implied by these files.

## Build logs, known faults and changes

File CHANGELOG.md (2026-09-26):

Version 1.1.0
# Changelog

All notable changes to this project will be documented in this file.

The format is based on [Keep a Changelog](https://keepachangelog.com/en/1.1.0/),
and this project adheres to [Semantic Versioning](https://semver.org/spec/v2.0.0.html).

## [TODO]
- Complete revision 15 prototype acceptance (see docs/rev15-assembly.md).

## [Unreleased] — Revision 16
### Added
- D3 BAT54,215 RX clamp to the Waveshare module 3.3 V rail through J4 pin 3 (issue #3).
- Project-local clamp symbol and retained custom RJ12 footprint.
- Enclosure CAD assessment and reproducible same-case RJ12 opening adjustment; retain 1.2 mm for the original 1.3 mm slot.
- Sample fabrication/assembly outputs and a functional acceptance checklist.
- Pin-adjacent VIN/RX/TX/GND labels for J3.
- PCBWay carrier BOM excluding already-purchased Waveshare modules, SMT-only centroid, and nominated supplier links for all carrier parts.

### Changed
- Updated tracks for rev 16 - no functional changes
- R3 TX base resistor from 1 kΩ to 560 Ω (issue #4; called R4 in older revisions). R4 stays 100 kΩ.
- J1/J2 to Ckmtw R-RJ11R06P-A000 (LCSC C2902699), with new drilled footprint and connector-region routing. Larger tab-down body requires enclosure/retention review.
- C1/C2/C3/C5 and L1 to current production/active-listed parts; record capacitor DC-bias qualification limits.
- Obsolete DIP-24 socket to J4/J5 Samtec SSW-109-01-T-S nine-position socket strips with manufacturer-derived 1.04 mm drill pattern.

### Validation status
- Prototype revision; physical validation remains required. The rail clamp does not provide power-off isolation.
- PCBWay quote acceptance, exact-part allocation, connector fit on the 1.2 mm board and module installation remain required before assembly.

## [1.1.0] - 2026-08-01
### Changed
- Set the board thickness to 1.2mm instead of default 1.6mm
### Fixed
- Rev 14 - Fixed TX circuit to handle 12v as well as 7v

## [1.0.0] - 2026-04-01
### Fixed
- Rev 13 - Fixed pinout for transistor
- Rev 13 - Tightend up layout for TX and RX components

## [0.10.2] - 2026-03-15
### Changed
- Rev 12 - fixed error in connecting vias shorting gnd to Net D2-K 
- Rev 12 - tidy up routing of D2

## [0.10.1] - 2026-02-26
### Changed
- Rev 11 - changed RJ12 connectors to 5324 6P6C pieces and updated pcb
- Rev 11 - additional gnd connecting vias under buck (U1)

## [0.10.0] - 2026-02-23
### Added
- Added Licence: CERN Open Hardware Licence Version 2 - Permissive

### Changed
- Rev 10 - moved C5 closer to U1
- Rev 10 - added via under U1
- Rev 10 - minor layout improvements.
- Rev 10 - Updated all part numbers and use MPN instead of PartNum
- Cleaned up some documentation

## [0.0.9] - 2026-02-17
### Added
- Updated readme.md file and include power calculation reference and docs.
- Added 3d model files - thanks @alangarf

### Changed
- Rev 9 - Moved the power buck to surface mount component LM2678S-5.0/NOPB
- Rev 9 - Moved the transistor to a SMD
- Rev 9 - Added copper pour for GND on both sides
- Rev 9 - Tided up annotations
- Rev 9 - Reorient header and move labelling closer

## [0.0.8] - 2026-02-16

### Added
- Initial commit of to GitHub
- RX, TX and Power circuits created
- Tested RX circuit works
- Reworked and tested TX circuit

### Changed
- Rev 6 - Reorient board to allow all plugs on one side
- Rev 7 - Reorient power circuit again to make cleaner
- Rev 8 - Updated all footprints to correct specs
- Rev 8 - Updated components to include part numbers
- Rev 8 - Respecced the power circuit based on TI toolins

### Fixed
- Fixed all the DRC rule violations and all but one of the ERC issues
- Make the component imports be relative paths
- Fixed last ERC consistency issue - modified symbol needed an update

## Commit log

2026-02-13 Add minimal project files for kicad
    [AstralPool.kicad_pcb, AstralPool.kicad_sch]
2026-02-14 - Cleaned up all but three of the ERC failures
    [AstralPool.kicad_sch]
2026-02-14 ### Fixed - Fixed all the DRC rule violations and all but one of the ERC issues - Make the component imports be relative paths
    [AstralPool.kicad_pcb, AstralPool.kicad_sch]
2026-02-14 ### Fixed - Fixed last ERC consistency issue - modified symbol needed an update
    [AstralPool.kicad_sch]
2026-02-14 Minor cleanups
    [AstralPool.kicad_pcb]
2026-02-14 ### Changed - Reorient board to allow all plugs on one side
    [AstralPool.kicad_pcb]
2026-02-14 ### Changed - Rev 7 - Reorient power circuit again to make cleaner
    [AstralPool.kicad_pcb]
2026-02-16 ### Added - Reworked and tested TX circuit
    ### Changed
    - Rev 8 - Updated all footprints to correct specs
    - Rev 8 - Updated components to include part numbers
    - Rev 8 - Respecced the power circuit based on TI toolins
    [AstralPool.kicad_pcb, AstralPool.kicad_sch]
2026-02-16 Added 3D models to help picture board
    [52018-6646.stp, AstralPool.kicad_pcb, DIP-24_18.0mmx34.29mm_W15.24mm.step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]
2026-02-17 ### Changed - Rev 9 - Moved the power buck to surface mount component LM2678S-5.0/NOPB - Rev 9 - Moved the transistor to a SMD - Rev 9 - Added copper pour for GND on both sides - Rev 9 - Tided up ann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
    [AstralPool.kicad_pcb, AstralPool.kicad_sch]
2026-02-17 ### Changed - Rev 9 - Reorient header and move labelling closer
    [AstralPool.kicad_pcb]
2026-02-17 Minor tweaks to export and versioning
    [AstralPool.kicad_sch]
2026-02-17 ### Changed - Rev 10 - moved C5 closer to U1 - Rev 10 - added via under U1 - Rev 10 - minor layout improvements.
    [AstralPool.kicad_pcb, AstralPool.kicad_sch]
2026-02-19 ### Changed - Rev 10 - Updated all part numbers and use MPN instead of PartNum
    [AstralPool.kicad_pcb, AstralPool.kicad_sch]
2026-02-23 Rename to generic PoolController
    [PoolController.kicad_pcb, PoolController.kicad_sch]
2026-02-24 ### Changed - Rev 11 - changed RJ12 connectors to 5324 6P6C pieces and updated pcb - Rev 11 - additional gnd connecting vias under buck (U1)
    [PoolController.kicad_pcb, PoolController.kicad_sch]
2026-03-15 ## [0.10.2] - 2026-03-15 ### Changed - Rev 12 - fixed error in connecting vias shorting gnd to Net D2-K - Rev 12 - tidy up routing of D2
    [PoolController.kicad_pcb]
2026-04-01 Version 1.0.0 - Rev 13 of board.
    [PoolController.kicad_pcb, PoolController.kicad_sch]
2026-04-05 [Changed] Set the board thickness to 1.2mm instead of default 1.6mm
    [PoolController.kicad_pcb]
2026-08-01 ### Fixed - Rev 14 - Fixed TX circuit to handle 12v as well as 7v
    [PoolController.kicad_pcb, PoolController.kicad_sch]
2026-09-26 Clean up track and update to rev16
    [PoolController.kicad_pcb, PoolController.kicad_sch]

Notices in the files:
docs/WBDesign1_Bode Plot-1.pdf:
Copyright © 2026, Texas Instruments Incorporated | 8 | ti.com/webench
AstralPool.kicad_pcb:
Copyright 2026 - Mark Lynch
